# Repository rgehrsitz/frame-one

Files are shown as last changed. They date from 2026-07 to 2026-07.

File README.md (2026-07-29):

# Frame One

**A calm, local-first e-paper status plate for a developer's desk.**

Frame One turns a Raspberry Pi Zero 2 W and a 7.5-inch Waveshare e-paper panel into a long, low dashboard for weather, AI allowance, Gmail unread count, and one daily quote. It is designed for slow, deliberate updates—not a constantly moving screen.

> **Early prototype:** the deterministic renderer, weather, quote, automatic Claude Code allowance capture, Codex, Gmail unread adapters, refresh service, and a fit-proven desk enclosure are ready. Gmail and Codex each require one explicit local sign-in before their first live use.

## What it will show

- Current conditions and a Today / Tonight / Tomorrow forecast
- Claude five-hour and weekly allowance, read on-device so the panel stays standalone
- Codex rate-limit windows through the local App Server
- Gmail unread count only—never subjects or message content
- One live Quote of the Day

See [DESIGN.md](DESIGN.md) for the exact screen system and [DATA_SOURCES.md](DATA_SOURCES.md) for provider, privacy, and refresh decisions.

## Planned hardware

| Part | Choice |
| --- | --- |
| Compute | Raspberry Pi Zero 2 W |
| Display | Waveshare 7.5-inch, 800 × 480 black-and-white e-paper HAT |
| Power | 5 V USB power supply |
| Storage | microSD card |
| Enclosure | A magnetic two-piece desk frame for the Waveshare 7.5-inch panel |

The enclosure is the fit-proven magnetic two-piece frame in
[`enclosure/EInk7.5-Frame-Magnets-4x2mm.3mf`](enclosure/EInk7.5-Frame-Magnets-4x2mm.3mf).
It is designed for the Waveshare 7.5-inch (800 × 480) display, a Raspberry Pi
Zero 2 W, and eight 4 × 2 mm magnets. See the
[enclosure notes](enclosure/README.md) before printing.

## Try the renderer

Requires Python 3.11+ and Pillow.

```sh
python3 -m pip install -e .
frame-one \
  --input samples/dashboard-state.json \
  --output output/dashboard.png
```

Or, without installing the package:

```sh
PYTHONPATH=src python3 -m frame_one.cli \
  --input samples/dashboard-state.json \
  --output output/dashboard.png
```

The result is a strict 1-bit 800 × 480 PNG suitable for the target panel.

Frame One bundles Barlow Condensed SemiBold, IBM Plex Mono Medium, and IBM Plex
Serif Italic so the dashboard looks the same on the Pi and on a development
computer. Their license files live in `src/frame_one/assets/fonts/`. Set
`FRAME_ONE_DISPLAY_FONT`, `FRAME_ONE_MONO_FONT`, or `FRAME_ONE_SERIF_FONT` only
to intentionally override those defaults.

### Show it on the Waveshare panel

Frame One supports the monochrome 800 × 480 Waveshare 7.5-inch V2 panel through
Waveshare's official `epd7in5_V2` library. First follow Waveshare's demo setup
and confirm that their test image works. The driver uses Raspberry Pi OS's
`spidev`, `gpiozero`, and `lgpio` modules. If Frame One has its own virtual
environment, create it with access to those system packages:

```sh
python3 -m venv --system-site-packages ~/frame-one/.venv
```

Then install Frame One in that environment and send the sample screen:

```sh
source ~/frame-one/.venv/bin/activate
python -m pip install -e ~/frame-one

frame-one \
  --input ~/frame-one/samples/dashboard-state.json \
  --output ~/frame-one/output/dashboard.png \
  --display waveshare-7in5-v2
```

The display adapter performs one full, clean refresh and then puts the panel to
sleep. It loads the official driver from
`~/waveshare-e-paper/RaspberryPi_JetsonNano/python/lib` by default. Set
`FRAME_ONE_WAVESHARE_LIB` if you cloned it elsewhere.

### Live Quote of the Day

Add `--live-quote` to fetch a fresh daily quote from ZenQuotes into memory for that render:

```sh
PYTHONPATH=src python3 -m frame_one.cli \
  --input samples/dashboard-state.json \
  --output output/dashboard.png \
  --live-quote
```

Frame One stores an accepted daily quote in the same local state cache used for
the other dashboard values, so a normal refresh does not restore the sample
placeholder. It expires after two days if the 2:00 AM fetch cannot recover; no
bundled quote list or separate quote file exists. ZenQuotes attribution belongs
in the eventual local setup/about page.

### Automatic Pi refresh

The supplied systemd units make the Pi self-starting: weather, Claude, Codex,
and Gmail poll every five minutes from 6:00 AM through midnight, then hourly
overnight. A separate run at 2:00 AM local time also fetches the daily quote.
Both use the same lock, so the e-paper panel is never driven by two refreshes
at once. A poll only refreshes the physical panel when the rendered pixels
change; the changing header timestamp alone cannot trigger a refresh. The
system timer is persistent, so a missed run is made up once after a reboot when
the network becomes available.

Set the location as explicit coordinates—never a street address—in the local,
owner-readable configuration file:

```sh
install -d -m 700 ~/.config/frame-one
install -m 600 deploy/systemd/dashboard.env.example ~/.config/frame-one/dashboard.env
# Edit WEATHER_LATITUDE, WEATHER_LONGITUDE, and WEATHER_TIMEZONE as needed.
```

Install and enable the boot-persistent units:

```sh
sudo install -m 644 deploy/systemd/frame-one-refresh.service /etc/systemd/system/
sudo install -m 644 deploy/systemd/frame-one-refresh.timer /etc/systemd/system/
sudo install -m 644 deploy/systemd/frame-one-quote.service /etc/systemd/system/
sudo install -m 644 deploy/systemd/frame-one-quote.timer /etc/systemd/system/
sudo systemctl daemon-reload
sudo systemctl enable --now frame-one-refresh.timer frame-one-quote.timer
systemctl list-timers 'frame-one-*'
```

The five-minute timer starts about 30 seconds after boot, then continues on
five-minute wall-clock boundaries.

### Live weather

Open-Meteo needs no account or key for this personal dashboard. Provide an
explicit latitude and longitude—the software does not infer your location—and
it will replace the sample weather data for that render. A failed request falls
back to the last good forecast, then to `—`; it never blocks the other tiles.

```sh
frame-one \
  --input ~/frame-one/samples/dashboard-state.json \
  --output ~/frame-one/output/dashboard.png \
  --live-weather \
  --weather-latitude 40.0000 \
  --weather-longitude -75.0000 \
  --weather-timezone America/New_York \
  --display waveshare-7in5-v2
```

### Claude allowance — standalone (recommended)

The Pi reads your five-hour and weekly allowance directly, with no second
machine involved. Authorize it once:

```sh
frame-one-claude-login
```

It prints a URL. Open it in a browser on any machine, approve, then paste the
address bar back — the page will fail to load, which is expected; the code is
in the URL. The credential is written to `~/.config/frame-one/claude-oauth.json`
with `0600` permissions and refreshes itself from then on.

Refresh tokens do eventually expire outright. When that happens the Claude tile
reports `not authorized yet; run frame-one-claude-login` and shows `—`; re-run
the login command. That is a re-authorization, not a fault.

```sh
frame-one --input ~/frame-one/samples/dashboard-state.json \
  --output ~/frame-one/output/dashboard.png \
  --claude-oauth-credentials ~/.config/frame-one/claude-oauth.json
```

Two things to know before choosing this. The usage endpoint is **not part of
Anthropic's published API**, so it may change without notice — the provider
validates every field and shows `—` rather than guessing when it does. And the
credential carries the `user:inference` scope, meaning a token on this device
could in principle spend allowance, not only read it. Treat the Pi accordingly,
and revoke the credential by deleting the file if the device leaves your hands.

### Claude allowance via Claude Code (no extra credential)

Frame One uses Claude Code's documented **status-line** `rate_limits` object.
After an ordinary Claude Code response, it provides the five-hour and seven-day
usage percentages plus their exact reset timestamps. The collector preserves
only those four values—never a prompt, transcript, repository name, account
identifier, or credential.

This alternative needs no extra credential, but it only produces data in
**rendered interactive terminal sessions** — the Claude Code desktop app and
`claude -p` never invoke a status line, so neither produces a snapshot. It also
reports nothing while you are not actively working, and nothing at all about
usage from claude.ai. It requires the machine running Claude Code to reach the
Pi, so the panel is no longer standalone.

Install this repository on the machine where you run terminal `claude`, then add
the command below as Claude Code's `statusLine.command`. If you already use a
custom status line, call this collector from that wrapper rather than replacing
your existing command.

```sh
python3 -m pip install -e ~/frame-one
```

```json
{
  "statusLine": {
    "type": "command",
    "command": "frame-one-claude-statusline --output ~/.config/frame-one/claude-status.json --timezone America/New_York --sync-to YOUR_PI_USER@frame-one.local:~/.config/frame-one/claude-status.json --identity-file ~/.ssh/frame-one-pi"
  }
}
```

The optional `--sync-to` copies the tiny snapshot to the Pi only after a
successful Claude response and no more than once every 15 minutes. It needs a
one-time, passwordless SSH key setup; it never copies the Claude credential.
Then the Pi's normal render command reads the automatically generated file:

```sh
frame-one --input ~/frame-one/samples/dashboard-state.json \
  --output ~/frame-one/output/dashboard.png \
  --claude-status-file ~/.config/frame-one/claude-status.json
```

Codex is read from the local App Server rather than from browser
cookies, the desktop app, or token files. Once Codex CLI is installed and
signed in on the Pi, add `--live-codex` to a normal render command.

Gmail reads only `threadsUnread` from the `INBOX` label—the conversation count
shown by the Gmail interface, without inflating the badge when one thread has
multiple unread messages. First create a Google
Cloud project, enable the Gmail API, configure its OAuth consent screen, and
create a **Desktop** OAuth client. Download its JSON on the Pi to an ignored,
owner-readable path such as `~/.config/frame-one/google-client.json`. The
consent screen needs the restricted `gmail.readonly` scope; in Google testing
mode, add the mailbox owner as a test user.

Then, from a Mac terminal, create a temporary loopback tunnel:

```sh
ssh -N -L 8765:127.0.0.1:8765 rgehrsitz@frame-one.local
```

On the Pi, start the authorization command and open the printed URL in the Mac
browser:

```sh
frame-one-gmail-login \
  --client-secrets ~/.config/frame-one/google-client.json
```

It writes `~/.config/frame-one/gmail.token.json` with `0600` permissions. That
file is ignored by Git and contains the refreshable credential; Frame One uses
it only for INBOX label metadata and never asks for Gmail messages, senders,
subjects, or bodies. Add it to a normal render command with
`--gmail-token ~/.config/frame-one/gmail.token.json`.

## Verify

```sh
PYTHONPATH=src python3 -m unittest discover -s tests -v
```

## Privacy principles

- The Pi fetches only values necessary for the screen.
- Gmail uses read-only label metadata; no messages, senders, subjects, or bodies are displayed or logged.
- Claude and Codex allowances are read as allowance figures only — percentages and reset times, never conversations, prompts, or project data.
- Reading a meter through an undocumented vendor interface is allowed when it is the only thing that works; such providers fail to `—` rather than guess.
- Credentials stay on their local source device and are never committed. `.gitignore` excludes local secrets and generated dashboard output.

## Attribution

- Weather data: [Open-Meteo](https://open-meteo.com/)
- Daily quote provider: [ZenQuotes](https://zenquotes.io/)
- E-paper hardware: [Waveshare](https://www.waveshare.com/)

## License

[MIT](LICENSE) © 2026 Robert Gehrsitz. Third-party services, fonts, hardware designs, and logos retain their own licenses and terms.

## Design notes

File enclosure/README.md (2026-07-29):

# Frame One enclosure

Frame One uses the fit-proven magnetic enclosure in
[`EInk7.5-Frame-Magnets-4x2mm.3mf`](EInk7.5-Frame-Magnets-4x2mm.3mf). Open this
3MF directly in Bambu Studio or another compatible slicer; it contains the
front bezel and rear housing in the intended print profile.

## Compatible hardware

- Waveshare 7.5-inch, 800 × 480 e-paper display
- Raspberry Pi Zero 2 W (or Pi Zero 1/2 WH)
- Compatible Waveshare 7.5-inch display HAT and FPC adapter
- Eight 4 × 2 mm magnets and super glue

## Print and assembly

The included profile specifies 0.12 mm layers, two walls, and 12% infill. PLA
is the recommended material; PETG also works. Keep the supplied orientation
and painted supports unless a slicer preview shows they are not needed.

1. Print both parts in the 3MF and remove supports carefully.
2. Glue eight 4 × 2 mm magnets into the pockets, checking the polarity before
   the adhesive cures.
3. Set the display HAT's display switch to **B** and interface switch to **0**.
4. Connect the FPC cable to the e-paper adapter, then slide the display into
   the bezel without stressing the cable.
5. Stack the Pi and HAT below the panel, route the cable beneath the stack, and
   snap the rear housing onto the magnetic bezel.

Always shut the Pi down before disconnecting its power. The FPC cable and
e-paper glass are delicate: do not force either while closing the enclosure.

## Model provenance

This print profile is the supplied **E-Ink Weather Display Frame** by
`dbunndesign` and retains the license embedded in the 3MF: **MakerWorld
Exclusive License**. Do not modify or redistribute it outside the terms of
that license. The previous custom OpenSCAD enclosure and its generated STL
parts have been removed from this project.

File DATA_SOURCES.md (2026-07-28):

# Frame One — Data Sources and Privacy Contract

## Decision

Frame One is **local-first**. The Raspberry Pi fetches and renders only the small set of values needed for the screen; it does not send dashboard data to a separate cloud service and it never stores email contents, prompts, repositories, or agent transcripts.

The first release has four automated providers (weather, Gmail, Codex, and Claude).

**On undocumented interfaces.** An earlier draft of this document forbade private or undocumented endpoints outright. That rule was written when no working method for reading agent allowances had been found, and it hardened a dead end into policy: it ruled out the only interfaces that actually return this data, and left the Claude tile permanently empty. It is withdrawn.

Frame One may read a subscription meter through whatever interface its vendor actually exposes, documented or not, using credentials the account owner authorizes on their own device. The tradeoff is accepted knowingly: undocumented interfaces carry no compatibility promise and may break without notice, so each such provider must fail closed to `unavailable` rather than fabricate a value. What remains non-negotiable is below.

## Common provider contract

Every provider returns this envelope to the renderer:

```json
{
  "provider": "weather",
  "state": "ok",
  "updated_at": "2026-07-25T10:00:00-04:00",
  "stale_after_seconds": 5400,
  "data": {}
}
```

`state` is one of `ok`, `unavailable`, `needs_setup`, or `stale`. The renderer never invents a value: unavailable data displays an em dash and keeps the rest of the screen useful.

## Provider decisions

| Display block | Source | First-release decision | Refresh |
| --- | --- | --- | --- |
| Weather | Open-Meteo Forecast API | Automated, no account | Hourly |
| Gmail unread | Gmail API label metadata | Automated, OAuth read-only | Every 15 min |
| Claude allowance | Account OAuth (default) or Claude Code status line | Automated; OAuth runs standalone on the Pi | Every refresh round (OAuth) or event-driven (status line) |
| Codex allowance | Codex App Server | Automated after local ChatGPT sign-in | Every 15 min and on change |
| Quote | ZenQuotes daily endpoint | Automated, live-only | Daily |

### 1. Weather

**Provider:** [Open-Meteo Forecast API](https://open-meteo.com/en/docs).

**Cost:** no paid subscription, account, API key, or credit card is needed for this personal non-commercial dashboard. The free tier permits up to 10,000 calls per day; Frame One will make roughly 24 hourly forecast calls per day. The forecast data is CC BY 4.0, so Frame One will include “Weather: Open-Meteo” with the required attribution in its local setup/about screen.

**Configuration:** the setup screen stores a user-chosen latitude, longitude, timezone, and temperature unit locally on the Pi. It must never infer or transmit the user's location to any service other than the weather provider.

**Request shape:** request current conditions plus daily `temperature_2m_max`, `temperature_2m_min`, `weather_code`, and `precipitation_probability_max`; request hourly `temperature_2m`, `weather_code`, `precipitation_probability`, and `is_day`. Open-Meteo documents these variables and its coordinate-based forecast endpoint.

**Screen mapping:**

- Header: current temperature and condition icon.
- Forecast strip: Today high/low; Tonight temperature and rain probability; Tomorrow high/low and rain probability.
- Rain probability appears only at 20% or higher. Otherwise use the space for the condition name or leave it quiet.

### 2. Gmail unread count

**Provider:** [Gmail API label resource](https://developers.google.com/workspace/gmail/api/reference/rest/v1/users.labels).

**OAuth scope:** `https://www.googleapis.com/auth/gmail.readonly`.

**Request:** `GET /gmail/v1/users/me/labels/INBOX`, then display `threadsUnread`. This reads label metadata only; it does not fetch subjects, senders, message bodies, attachments, or message IDs. Gmail documents both `messagesUnread` and `threadsUnread`; Frame One uses unread threads because that is the conversation count shown by Gmail's Inbox badge, while a thread can contain multiple unread messages.

**Authorization:** the account owner creates a Google Desktop OAuth client, enables the Gmail API, then approves the `gmail.readonly` scope once through `frame-one-gmail-login`. The Pi receives the callback over an SSH loopback tunnel, so the browser login and the token exchange remain between the account owner and the local device.

**Storage:** the refresh token is stored in an owner-readable (`0600`) local file restricted to the dashboard service account. The token and any raw Gmail response must never be written to logs or sent to another device.

**Fallback:** show `—` with a small “Gmail setup required” message until OAuth setup is complete. No email-derived content is ever shown on the panel.

### 3. Claude allowance

Claude's paid plans expose five-hour and weekly limits. There are two ways to read them, and Frame One supports both.

**Primary — account OAuth (standalone).** The Pi holds its own OAuth credential, authorized once by the account owner in a browser, and reads the five-hour and seven-day windows directly. This is the only method that works with no second machine, so it is the default for a standalone panel. The endpoint is not part of Anthropic's published API surface and may change without notice; the provider therefore validates every field and reports `unavailable` rather than guessing when the shape is not what it expects.

**Alternative — Claude Code status line (no extra credential).** Claude Code's documented status-line contract includes `rate_limits.five_hour` and `rate_limits.seven_day` for Claude.ai Pro/Max subscribers after the first response in a session. Each window supplies `used_percentage` and a Unix `resets_at` timestamp. Two limits are worth knowing before choosing it: it fires only in **rendered interactive terminal sessions** — the Claude Code desktop app and `claude -p` never invoke it — and it therefore reports nothing while you are not actively working, and nothing at all about usage from claude.ai.

**Automatic collector:** a small status-line command receives the local JSON event and reduces it to only the following state:

```json
{
  "source": "claude-code-statusline",
  "rate_limits": {
    "five_hour": {
      "percent_remaining": 63,
      "resets_at": "2026-07-25T14:15:00-04:00"
    },
    "seven_day": {
      "percent_remaining": 81,
      "resets_at": "2026-07-28T00:00:00-04:00"
    }
  }
}
```

The collector performs no Claude request and stores no prompt, transcript, workspace, account identifier, or credential. The UI supports `—` for any unavailable meter.

**The SSH snapshot transport is the fallback path, not the default.** It applies only when the status-line collector is used instead of account OAuth. In that configuration a dedicated SSH key copies the snapshot to the Pi at most once every 15 minutes — so panel freshness is capped at 15 minutes unless `--sync-interval-seconds` is lowered. The key authenticates only to the Pi and is unrelated to Claude. With account OAuth configured, no SSH key, no second machine, and no transport are involved at all.

**Either way, only the meter is read.** Whichever method is configured, Frame One requests allowance percentages and reset timestamps and nothing else. It never reads conversations, prompts, transcripts, or project data, and never displays an account identifier on the panel.

References: [Claude Code status-line contract](https://code.claude.com/docs/en/statusline) and [Use Claude Code with a Pro or Max plan](https://support.claude.com/en/articles/11145838-use-claude-code-with-your-pro-or-max-plan).

### 4. Codex allowance

Codex usage is plan-dependent and can be shared with other agentic features. For this dashboard, use OpenAI's **Codex App Server**, which runs locally on the Pi and answers `account/rateLimits/read` without a second machine. It is preferred over any web interface because it is a supported local protocol that needs no extra credential, not because other interfaces are off-limits.

**Provider:** launch the local app server on the Pi and call `account/rateLimits/read`; subscribe to `account/rateLimits/updated` to invalidate the cached value. The official App Server documentation lists both methods.

**Authentication:** the user completes the ChatGPT/device-code sign-in once on the Pi with `codex login`. Frame One talks to the App Server over its local stdio protocol and leaves Codex's own credential store alone — not as a restriction, but because the App Server already handles auth, so there is nothing to gain by touching it. Codex tokens are never logged or transmitted.

**Screen mapping:** map the returned rate-limit windows to the two Codex lines in the UI. Preserve the server-provided labels and reset times rather than assuming a fixed five-hour or weekly model. The secondary reset must include its calendar date as well as its time. If the account does not expose a secondary window, show `WEEK —`.

**Fallback:** if a plan does not return a dashboard-suitable window, show `—`. Never calculate a remaining allowance from task counts or token estimates.

References: [Codex App Server API overview](https://learn.chatgpt.com/docs/app-server#api-overview-1), [Using Codex with a ChatGPT plan](https://help.openai.com/en/articles/11369540-using-codex-with-your-chatgpt-plan), and [Codex rate card](https://help.openai.com/en/articles/20001106-codex-rate-card).

### 5. Daily quote

**Provider:** [ZenQuotes' daily endpoint](https://docs.zenquotes.io/zenquotes-documentation/). It needs no API key at this scale and provides one daily quote.

Frame One fetches the quote during the 2:00 AM dashboard refresh. The adapter
accepts only a short quote with an author; an unsuitable or unreachable response
is `unavailable`. A successful daily quote is kept in the existing local
last-known-good state cache for up to two days, so normal five-minute renders do
not restore the sample placeholder. There is no bundled collection, recent-quote
list, or separate quote file. Include the required `Quotes: ZenQuotes.io`
attribution in the local setup/about screen.

## Refresh and failure policy

- The renderer checks sources on their schedules but redraws only when visible data changed. The panel write is skipped when the rendered pixels are identical, so an idle screen does not flash every five minutes.
- A refresh round runs every 5 minutes, collapsing to hourly between midnight and 6AM.
- Gmail is polled every 15 minutes; weather hourly; the live quote is fetched daily.
- A manual refresh button is available for a deliberate update.
- **Retry before giving up.** Every provider in a round shares one wall-clock deadline. Network sources retry three times with exponential backoff, the Codex App Server twice, and purely local file reads once — retrying a file read cannot change its answer, it only consumes the round's budget.
- **No provider aborts the round.** An unavailable provider never blocks the rest of the display.
- **Last-known-good.** A successful fetch is stamped with `updated_at` and `stale_after_seconds` and cached locally. If a later refresh fails, the tile keeps showing that value with `state: "stale"` until it ages past its window; then it becomes `—`. The renderer treats `ok` and `stale` alike, so a brief network blip does not blank a tile.
- Do not expose error messages, OAuth tokens, location coordinates, account email addresses, or stack traces on the e-paper panel.

## Implementation status

- Open-Meteo, ZenQuotes, the Claude Code status-line collector, the Codex App Server reader,
  and the Gmail INBOX-label reader are implemented.
- The retry, last-known-good, and refresh-cadence layer is implemented: every provider
  retries under one shared deadline, falls back to its last good value while that value is
  still inside `stale_after_seconds`, and then shows `—`. No provider can abort a round.
- The Gmail reader includes a local authorization command, but still requires a
  user-created Google Desktop OAuth client and one browser approval before its
  first live use.
- The Codex reader requires Codex CLI plus a local `codex login` on the Pi; it invokes only
  `account/rateLimits/read` over stdio JSON-RPC. The Pi runs 64-bit Raspberry Pi OS, which
  the `linux-arm64` build supports.
- **Not yet implemented:** the account-OAuth Claude provider. Until it lands, the Claude tile
  depends on the status-line collector, which only fires in interactive terminal sessions.

## Standalone status

Weather, the quote, Gmail, and Codex all run on the Pi with no second machine. Claude is the
one tile that cannot: the status-line collector only produces data on whichever machine runs
interactive terminal `claude`. The account-OAuth provider above is what closes that gap and
makes the panel fully standalone.

## Build order

1. Implement the shared state assembler and renderer using fixed sample data.
2. Add Open-Meteo, then Gmail OAuth / unread metadata.
3. Add the Codex App Server adapter, then the Claude Code status-line collector.
4. Add retry, last-known-good, and the refresh cadence.
5. Complete the Gmail authorization ceremony on the Pi.
6. Add the account-OAuth Claude provider so the panel needs no second machine.
7. Install the systemd timer that drives the refresh cadence.

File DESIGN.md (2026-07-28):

# Frame One — Display Design

## Intent

Frame One is a **slow, calm developer weather station**: in two seconds, it answers how the day looks, how much AI capacity remains, and whether email needs attention. It is deliberately an e-paper status plate, not a constantly changing dashboard.

The memorable impression is *a beautifully printed instrument panel for a developer's day*.

## Screen system

The Waveshare panel is 800 × 480 pixels, black and white. The product design therefore uses only solid black ink and white paper; no grayscale, color coding, progress rings, shadows, or charts. Information hierarchy comes from scale, alignment, and rules.

| Region | Pixels | Purpose |
| --- | --- | --- |
| Header | `y: 0–92` | Date, last-updated stamp, current weather |
| Forecast strip | `y: 92–140` | Today, tonight, tomorrow |
| Status grid | `y: 140–410` | Claude, Codex, Gmail |
| Quote footer | `y: 410–480` | One short, attributed live quote per day |

The status grid has three equal columns: `x: 0–267`, `267–534`, and `534–800`. Use one-pixel rules only at region and column boundaries. Leave a clear gap between the large allowance figure and its lower reset information; the figure must never compete with the operational details.

## Typography

- **Display numbers and headings:** Barlow Condensed SemiBold. Its tall, narrow shapes make percentages and time readable from across a desk without wasting horizontal space.
- **Supporting labels:** IBM Plex Mono Medium. Its mechanical, measured character supports the instrument-panel feeling and keeps reset times easy to scan.
- **Quote:** IBM Plex Serif Italic. This is the sole human, editorial note in an otherwise utilitarian screen.

### Weather marks

The header uses four bespoke monochrome instrument marks: clear, partly cloudy,
cloudy, and rain. They are drawn from simple circles, arcs, and 2-pixel lines
inside the renderer rather than supplied by emoji, an icon font, or an external
asset. This keeps them crisp and dependable on a 1-bit panel. The partly-cloudy
mark uses a rayless sun behind one clean cloud silhouette: the symbol must be
legible at a glance, not illustrate the whole sky.

The production renderer bundles these open-source font files with the app rather than relying on a network request. Their license files live beside the font assets.

| Role | Font / size |
| --- | --- |
| Updated stamp | IBM Plex Mono Medium, 18 px |
| Header date / weather | Barlow Condensed SemiBold, 28 px |
| Forecast item | IBM Plex Mono Medium, 18 px |
| Column heading | Barlow Condensed SemiBold, 38 px |
| Usage value / unread count | Barlow Condensed SemiBold, 80 px |
| Primary usage label | Barlow Condensed SemiBold, 24 px |
| Reset detail | IBM Plex Mono Medium, 14 px |
| Quote / attribution | IBM Plex Serif Italic 20 px / IBM Plex Mono Medium 16 px |

## Color

```css
:root {
  --paper: #ffffff;  /* panel white */
  --ink: #000000;    /* panel black */
}
```

The desktop preview may use `#f7f5ef` as its page background to evoke paper, but production output must remain strict 1-bit black and white.

## Content rules

- The header always stays stable: date left, last-updated stamp centered, current condition right. It is not a live clock; it changes only when an intentional screen refresh occurs.
- The forecast strip shows **Today**, **Tonight**, and **Tomorrow**. Every label uses the same 20 px condensed face; every value uses the same 14 px mono face. Use tight temperature pairs (`78°/65°`), not padded ones, and preserve the type scale rather than shrinking a long third item.
- Claude and Codex window labels use Barlow Condensed SemiBold so their short words remain compact and naturally spaced. IBM Plex Mono is reserved for the changing, exact time or percentage in Claude's aligned detail rows.
- Claude shows its two distinct allowances as `5-HOUR LEFT` and `WEEK LEFT`, each paired directly with a plainly labelled reset. The weekly reset always includes both date and time. Its two short detail rows align labels left and values right; never run label and time together as one long monospaced sentence.
- Codex is a weekly-budget display: it shows `WEEK LEFT` and one full date-and-time reset. When Codex App Server returns both a shorter primary window and a weekly secondary window, use the actual weekly secondary window. Missing data renders as an em dash—never guessed or sample-looking values.
- Gmail shows only unread count. It must not expose subject lines or personal message content.
- Quotes are short, attributed, and fetched once at the daily refresh. There is no quote cache or fallback.

## Refresh rules

- Render only when data has changed or on the scheduled cadence.
- Working hours: check data every 15 minutes; refresh the panel at most once per 15 minutes.
- Overnight: check hourly; refresh only for meaningful changes.
- Weather: update hourly. Quote: update daily. Manual refresh remains available.
- Periodically force a full panel refresh to clear ghosting; the exact interval will be tuned on the physical display.

## Do / don't

**Do** use large numerals, fixed layout positions, and whitespace because the display should remain legible from beside a monitor.

**Do** let a single forecast strip and a single daily quote add personality without competing with operational information.

**Don't** add live spinners, animations, tiny charts, or second-by-second agent states; they fight the e-paper medium.

**Don't** use red/yellow/green status semantics. On this screen, changing numbers and clear labels are more trustworthy than decorative alarms.

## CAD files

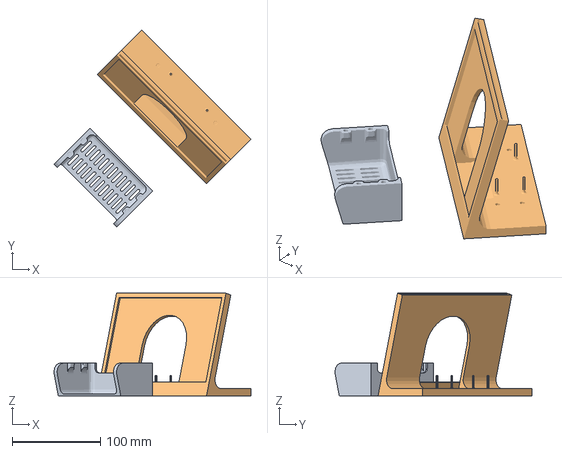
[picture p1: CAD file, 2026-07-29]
enclosure/EInk7.5-Frame-Magnets-4x2mm.3mf
222.7 x 222.7 x 116.0 mm
Waveshare7.5 - Lid - 4x2mm Magnet.stl
Waveshare7.5 - Frame - 4x2mm Magnet.stl

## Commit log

2026-07-25 Initial public prototype
2026-07-28 Tighten allowance detail typography
2026-07-28 Fix Codex allowance read closing stdin before the reply
    subprocess.run closes stdin as soon as the request is written, and the
    Codex App Server treats that EOF as a shutdown. It answered initialize
    and then exited before its backend round trip returned, so every call to
    account/rateLimits/read timed out and --live-codex reported unavailable
    every single time.
    Hold stdin open until the matching response arrives, with a watchdog
    timer bounding the wait, and skip the unrelated notifications the server
    interleaves on stdout. Raise the timeout to 30s for the Pi.
    The regression test drives a stand-in server that replies from a worker
    thread and exits on stdin EOF, reproducing the original failur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
2026-07-28 Add standalone Claude allowance and per-provider refresh resilience
    The Claude tile had never produced data. The status-line collector only
    fires in rendered interactive terminal sessions -- the desktop app and
    claude -p never invoke it -- so the snapshot was never written, and even
    when it works it needs the machine running Claude Code to reach the Pi.
    Add an account-OAuth provider that reads the five-hour and seven-day
    windows on-device, which is what lets the panel run with no second
    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
2026-07-28 feat: add printable desk enclosure
    [frame-one-desk-case.scad]
2026-07-28 Rebuild the plinth as a seating trough in the shared frame
    The plinth was authored in its own offset coordinate frame while its
    crops, its cable cut, and its assembly transform all assumed a centered
    part. That single mismatch produced three defects:
    - plinth_left/right cropped to +/-plinth_d/2 while the geometry actually
    spanned y -31..0.5, so the two exported halves totalled 16mm of depth
    against a designed 31.5mm. The printed stand was missing its rear.
    - The cable cut sat at y 13.08..15.52 with the plinth's maximum at 0.5,
    so it intersected nothing and removed no material at all.
    - rotate([90,0,0]) landed the broad base in mid-air and stood the narrow
    slab on the desk, inverting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
    [frame-one-desk-case.scad]
2026-07-28 Warn that the default part is not printable
    part defaults to "assembly", so opening the file and exporting straight
    away yields a 200 x 139 mm object that no 180 mm bed can print -- and the
    slicer is the first thing that says so, after the export.
    Echo a note to the console when the assembly renders, and give the README
    a footprint table plus a batch-export loop. Also record that parts come
    out in the assembly's frame (+Y up, +Z back), so the rear halves want a
    180-degree flip and the plinth halves a -90-degree rotation about X;
    without it the plinth imports standing on a 16 mm edge.
    Exported meshes are build output, so enclosure/stl/ is ignored.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
    [frame-one-desk-case.scad, frame-one-desk-case.stl]
2026-07-28 Add local Gmail OAuth authorization flow
2026-07-28 Match Gmail unread count to inbox threads
2026-07-29 Replace desk enclosure with magnetic 3MF
    [EInk7.5-Frame-Magnets-4x2mm.3mf, frame-one-desk-case.scad, frame-one-desk-case.stl]
2026-08-11 fix: use observations for current weather icon
2026-11-10 fix: report an expired Claude grant as needs_setup
    A refresh token that has expired or been revoked is the one failure
    retrying cannot mend, but the provider returned "unavailable" for it --
    the same answer it gives a network blip. The Pi therefore spent its full
    retry budget every ten minutes for ten weeks while the only trace was
    "claude: unavailable after retries", which blames the network for
    something only a person can fix.
    refresh.py already treats needs_setup as terminal and cli.py already
    knows to name the login command; that path simply never fired. Classify
    a 400/401/403 from the token endpoint carrying invalid_grant,
    invalid_client or unauthorized_client as ReauthorizationRequire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
2026-11-10 feat: say on the panel when Claude needs signing in again
    The allowance tile reported a lapsed authorization exactly as it reports
    a quiet network: an em dash. A log line nobody reads for ten weeks is
    not much better than silence, so put the reason on the glass.
    The Claude tile now drops its allowance rows rather than filling four
    slots with em dashes -- each would be unknown for the same single
    reason, and saying that reason once is worth more than repeating "-"
    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
2026-11-10 fix: keep the login listener from stalling or falling through
    Two faults found in review, both in the redirect listener.
    HTTPServer.timeout bounds only the wait for a connection. Once one is
    accepted the handler's reads block with no timeout of their own, so a
    browser preconnect -- a socket opened speculatively and left silent --
    held this single-threaded server forever: the deadline was never
    rechecked and the connection carrying the real redirect was never
    accepted. Cap each accepted connection by whatever is left of the
    authorization deadline.
    TimeoutError subclasses OSError, so running out of time was caught by
    the branch meant for "something already holds the port" and diverted
    into _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
